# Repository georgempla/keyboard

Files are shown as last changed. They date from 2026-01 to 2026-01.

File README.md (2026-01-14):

# George’s Keyboard

After many hours of work, I designed a custom mechanical keyboard featuring RGB LEDs, OLED displays, and rotary encoders. This project focuses on PCB planning, firmware research, CAD design, and represents my second hardware project ever.

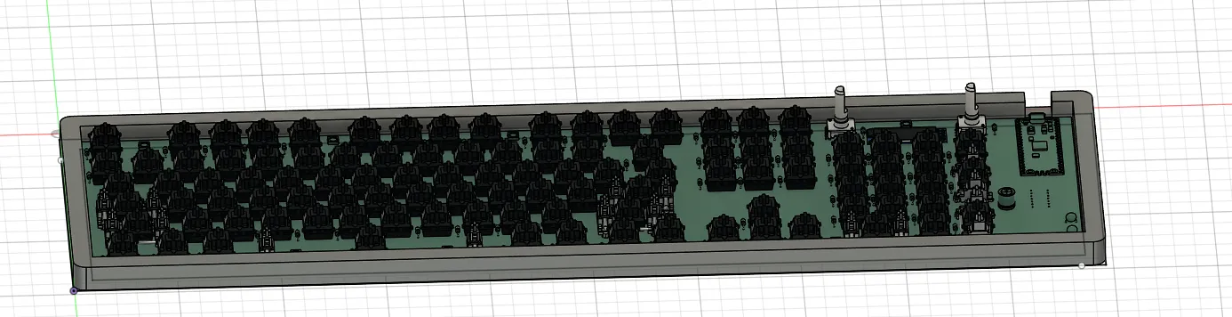
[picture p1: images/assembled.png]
Georgeskeyboardrender


---

## What This Project Is

This Project is a custom mechanical keyboard powered by a Raspberry Pi Pico. It has:
- Sections of addressable RGB LEDs
- Two rotary encoders with switches
- An OLED 0.91Inch display
- A custom PCB designed in KiCad
- A 3D-printed case that showcases the PCB

The goal of this project was to recreate my own keyboard layout while adding extra functionality and learning more about PCB design and KMK firmware.

---

## Inspiration

This was only my second project ever. While looking for ideas I realized that the inspiration was right in front of me: my own keyboard. After taking measurements and studying how keyboards in general are designed, I decided to recreate it while adding my own twist on the concept with LEDs, an OLED display, and rotary encoders.

---

## Challenges / What I Learned

This was the second PCB I havee ever designed, and the first one I designed completely on my own. Through this process, I learned:
- How to organize a KiCad project properly
- Better routing techniques
- How to recover from mistakes and reroute a board cleanly

Even though I had to redo parts of the design, the second iteration was much cleaner.

---

## Design Files

This project includes:
- A full keyboard schematic
- A routed PCB layout
- A 3D printable case design

Schematic | PCB Layout | Case
:--:|:--:|:--:
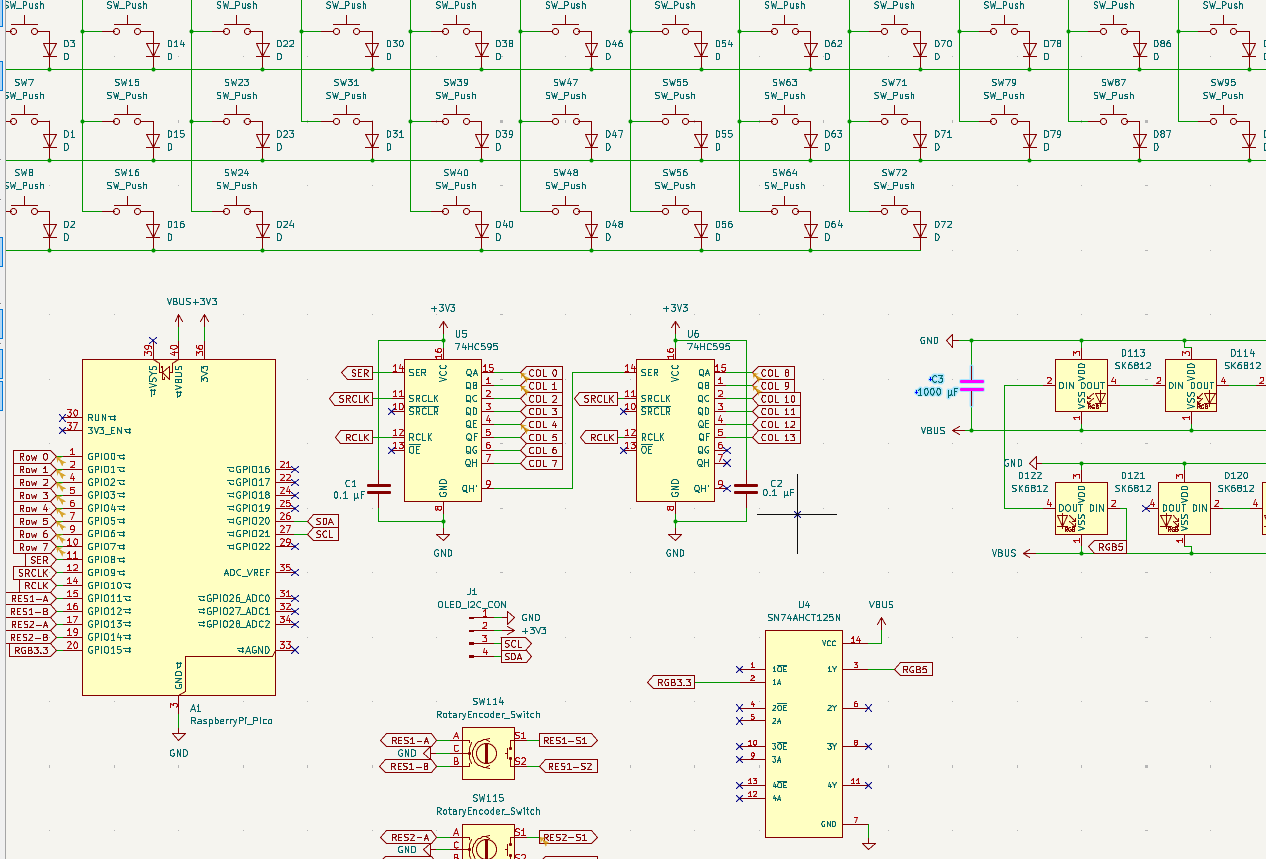
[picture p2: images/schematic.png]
schematic
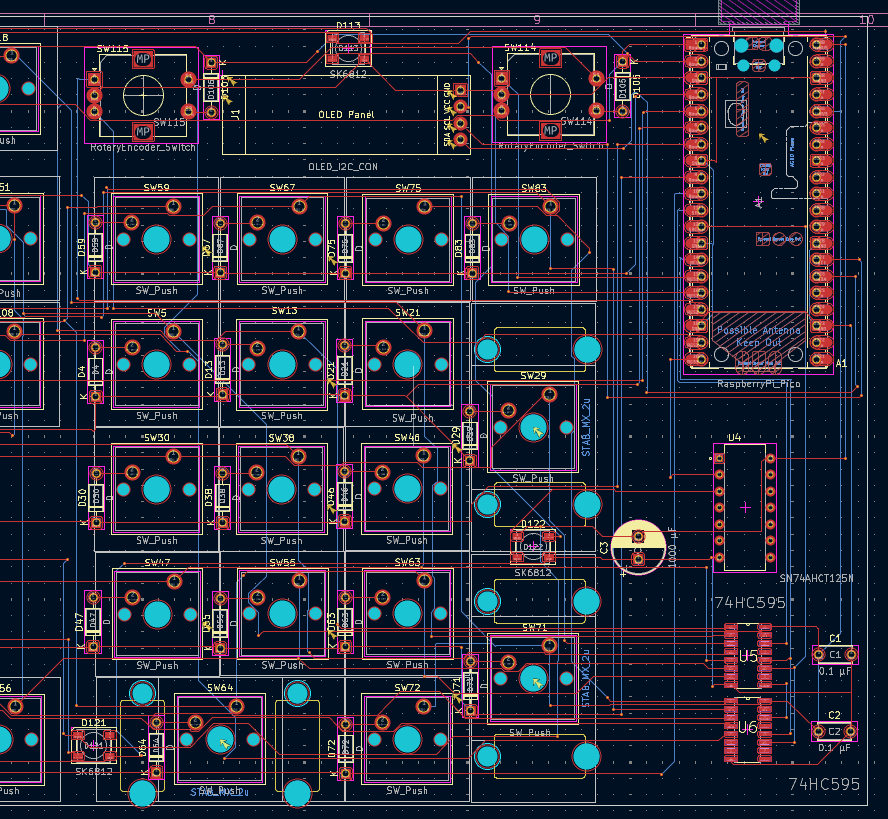
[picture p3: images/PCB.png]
pcb
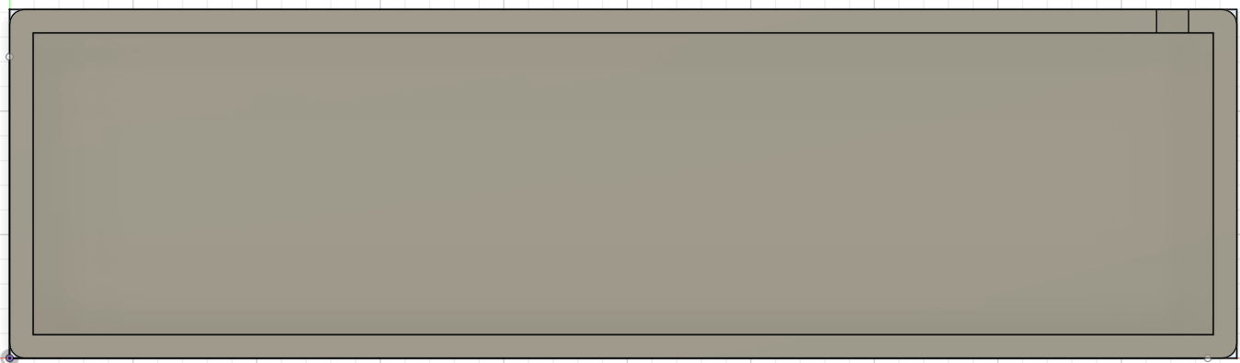
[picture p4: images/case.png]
case
 |  |  

---

## Firmware (Planned)

The firmware is currently written but *untested*, as the keyboard has not yet been assembled. Once the hardware is built I plan to:
- Flash the firmware to the Raspberry Pi Pico
- Test all keys, LEDs, encoders, and the OLED display
- Fix bugs and upload a finalized version

After testing this section will be updated with corrected code and flashing instructions.

---

## Bill of Materials (BOM)

### Electronics
- 1× Raspberry Pi Pico
- 1× OLED module (0.91", 128×32)
- 2× Rotary encoders (12 mm, 24 P/R, with switch)
- 10× SK6812 RGB LEDs
- 2× 74HCT595D shift registers
- 1× 74AHCT125
- 110× 1N4148 diodes
- 1× 1000 µF capacitor
- 2× 100 nF ceramic capacitors

### Mechanical
- Keychron K Pro switches (110 pieces)
- Glorious Stabilizers V2
- Mountain Dolomite A Backlit Keycap Set
- 3D printed case (`case.stl`)

---

## Next Steps

- Wait for approval
- Order the PCB
- Print the case
- Assemble and solder all components
- Test and debug firmware
- Update this README with build instructions

---

## Reflection

This project helped me evolve a lot as a designer. Compared to my first PCB, this one is cleaner, more complex, and better planned. Even though it isn't built yet, I learned a huge amount about schematics, routing, and hardware design through the process.

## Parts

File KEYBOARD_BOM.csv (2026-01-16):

Product name | Product description | Product amount | Product unit cost inc. Tax (€) | Product total cost (€) | Running total (€ with tax and shipping) | Notes | LINKS
OLED Module 0.91" 128x32 | OLED display module | 1 | 6.8 | 6.8 | 6.8 |  | https://grobotronics.com/oled-module-0.91-128x32-i2c-white.html
Rotary Encoder 12mm 24P/R with Switch | Rotary Encoder with Switch | 2 | 1.2 | 2.4 | 9.2 |  | https://grobotronics.com/rotary-encoder-12mm-24p-r-with-switch.html
74AHCT125 | Quad Level-Shifter | 1 | 0.5 | 0.5 | 9.7 |  | https://grobotronics.com/74ahct125-quad-level-shifter.html
SK6812 | LED SMD 5050 RGB Programmable | 10 | 0.3 | 3 | 12.7 |  | https://grobotronics.com/led-8mm-rgb-programmable-ws2812-clone.html
74HCT595D | Shift Register 8-Bit SMD | 2 | 0.8 | 1.6 | 14.3 |  | https://grobotronics.com/shift-register-8-bit-smd-74hct595d.html
Capacitor 1000uF | Electrolytic Capacitor 16V 1000uF | 1 | 0.2 | 0.2 | 16.7 | with 2.20 shipping from grobotronics for last 6 products | https://grobotronics.com/electrolytic-capacitor-16v-1000ufoem.html
Πυκνωτής 100nf | Πυκνωτής Κεραμικός 104(100nf) | 2 | 0.05 | 0.1 | 16.8 |  | https://nettop.gr/index.php/hlektronika/capacitors/ceramic-capacitor/pyknotis-keramikos-104-100nf.html
Raspberry Pi Pico | Raspberry Pi Pico without Headers | 1 | 4.2 | 4.2 | 21 |  | https://nettop.gr/index.php/raspberry-pi/pico/raspberry-pi-pico.html?src=raspberrypi
1N4148 | Diode - 1N4148 Small Signal Fast Switching Diode | 110 | 0.04 | 4.4 | 27.7 | with 2.30 shipping from nettop for last 3 products | https://nettop.gr/index.php/hlektronika/diode/diode-1n4148-small-signal-fast-switching-diode.html
Keychron K Pro Switches | Keychron K Pro Switches Πληκτρολογίου, 110-pack | 1 | 17.48 | 17.48 | 45.18 | in-store pickup | https://www.public.gr/product/gaming/pc-gaming/pc-gaming-accessories/diafora-pc-gaming-accessories/keychron-k-pro-switches-pliktrologiou-110-pack/2090270
Glorious Stabilizers V2 | Glorious Stabilizers V2 | 1 | 4.99 | 4.99 | 50.17 |  | https://shopflix.gr/p/SF-12868640/stabilizers-glorious-v2-gata1723-12843162
Mountain Dolomite A Backlit Keycap Set | Mountain Dolomite A Backlit Keycap Set | 1 | 5.25 | 5.25 | 60.42 | with 5 shipping from shopflix for last 2 products | https://www.skroutz.gr/s/57409660/Mountain-Dolomite-A-Backlit-Keycap-Set.html
PCB | PCB for JLCPCB | 42.33 | 42.33 | 42.33 | 102.75 | with cheapest shipping | https://shopflix.gr/p/SF-200097568/mountain-dolomite-a-backlit-keycap-set
 |  |  |  |  |  |  | https://jlcpcb.com

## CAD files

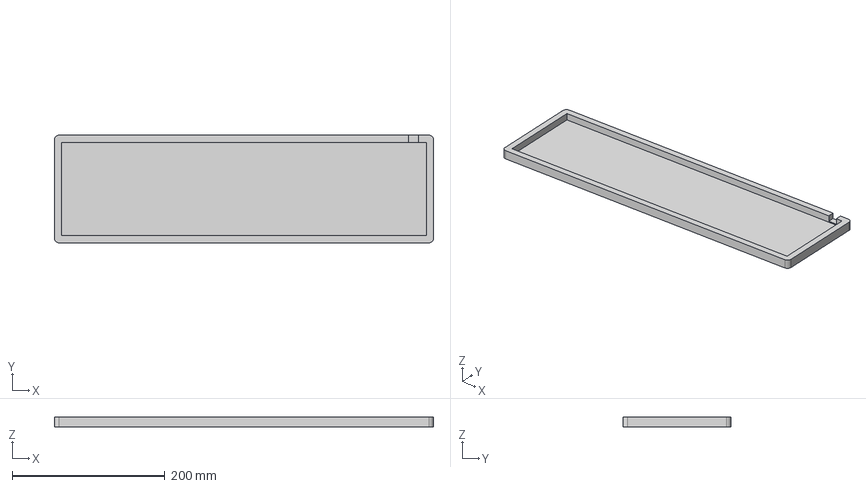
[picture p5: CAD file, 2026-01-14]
CAD/Keyboard.step
496.7 x 141.2 x 13.0 mm

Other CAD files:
CAD/case.stl

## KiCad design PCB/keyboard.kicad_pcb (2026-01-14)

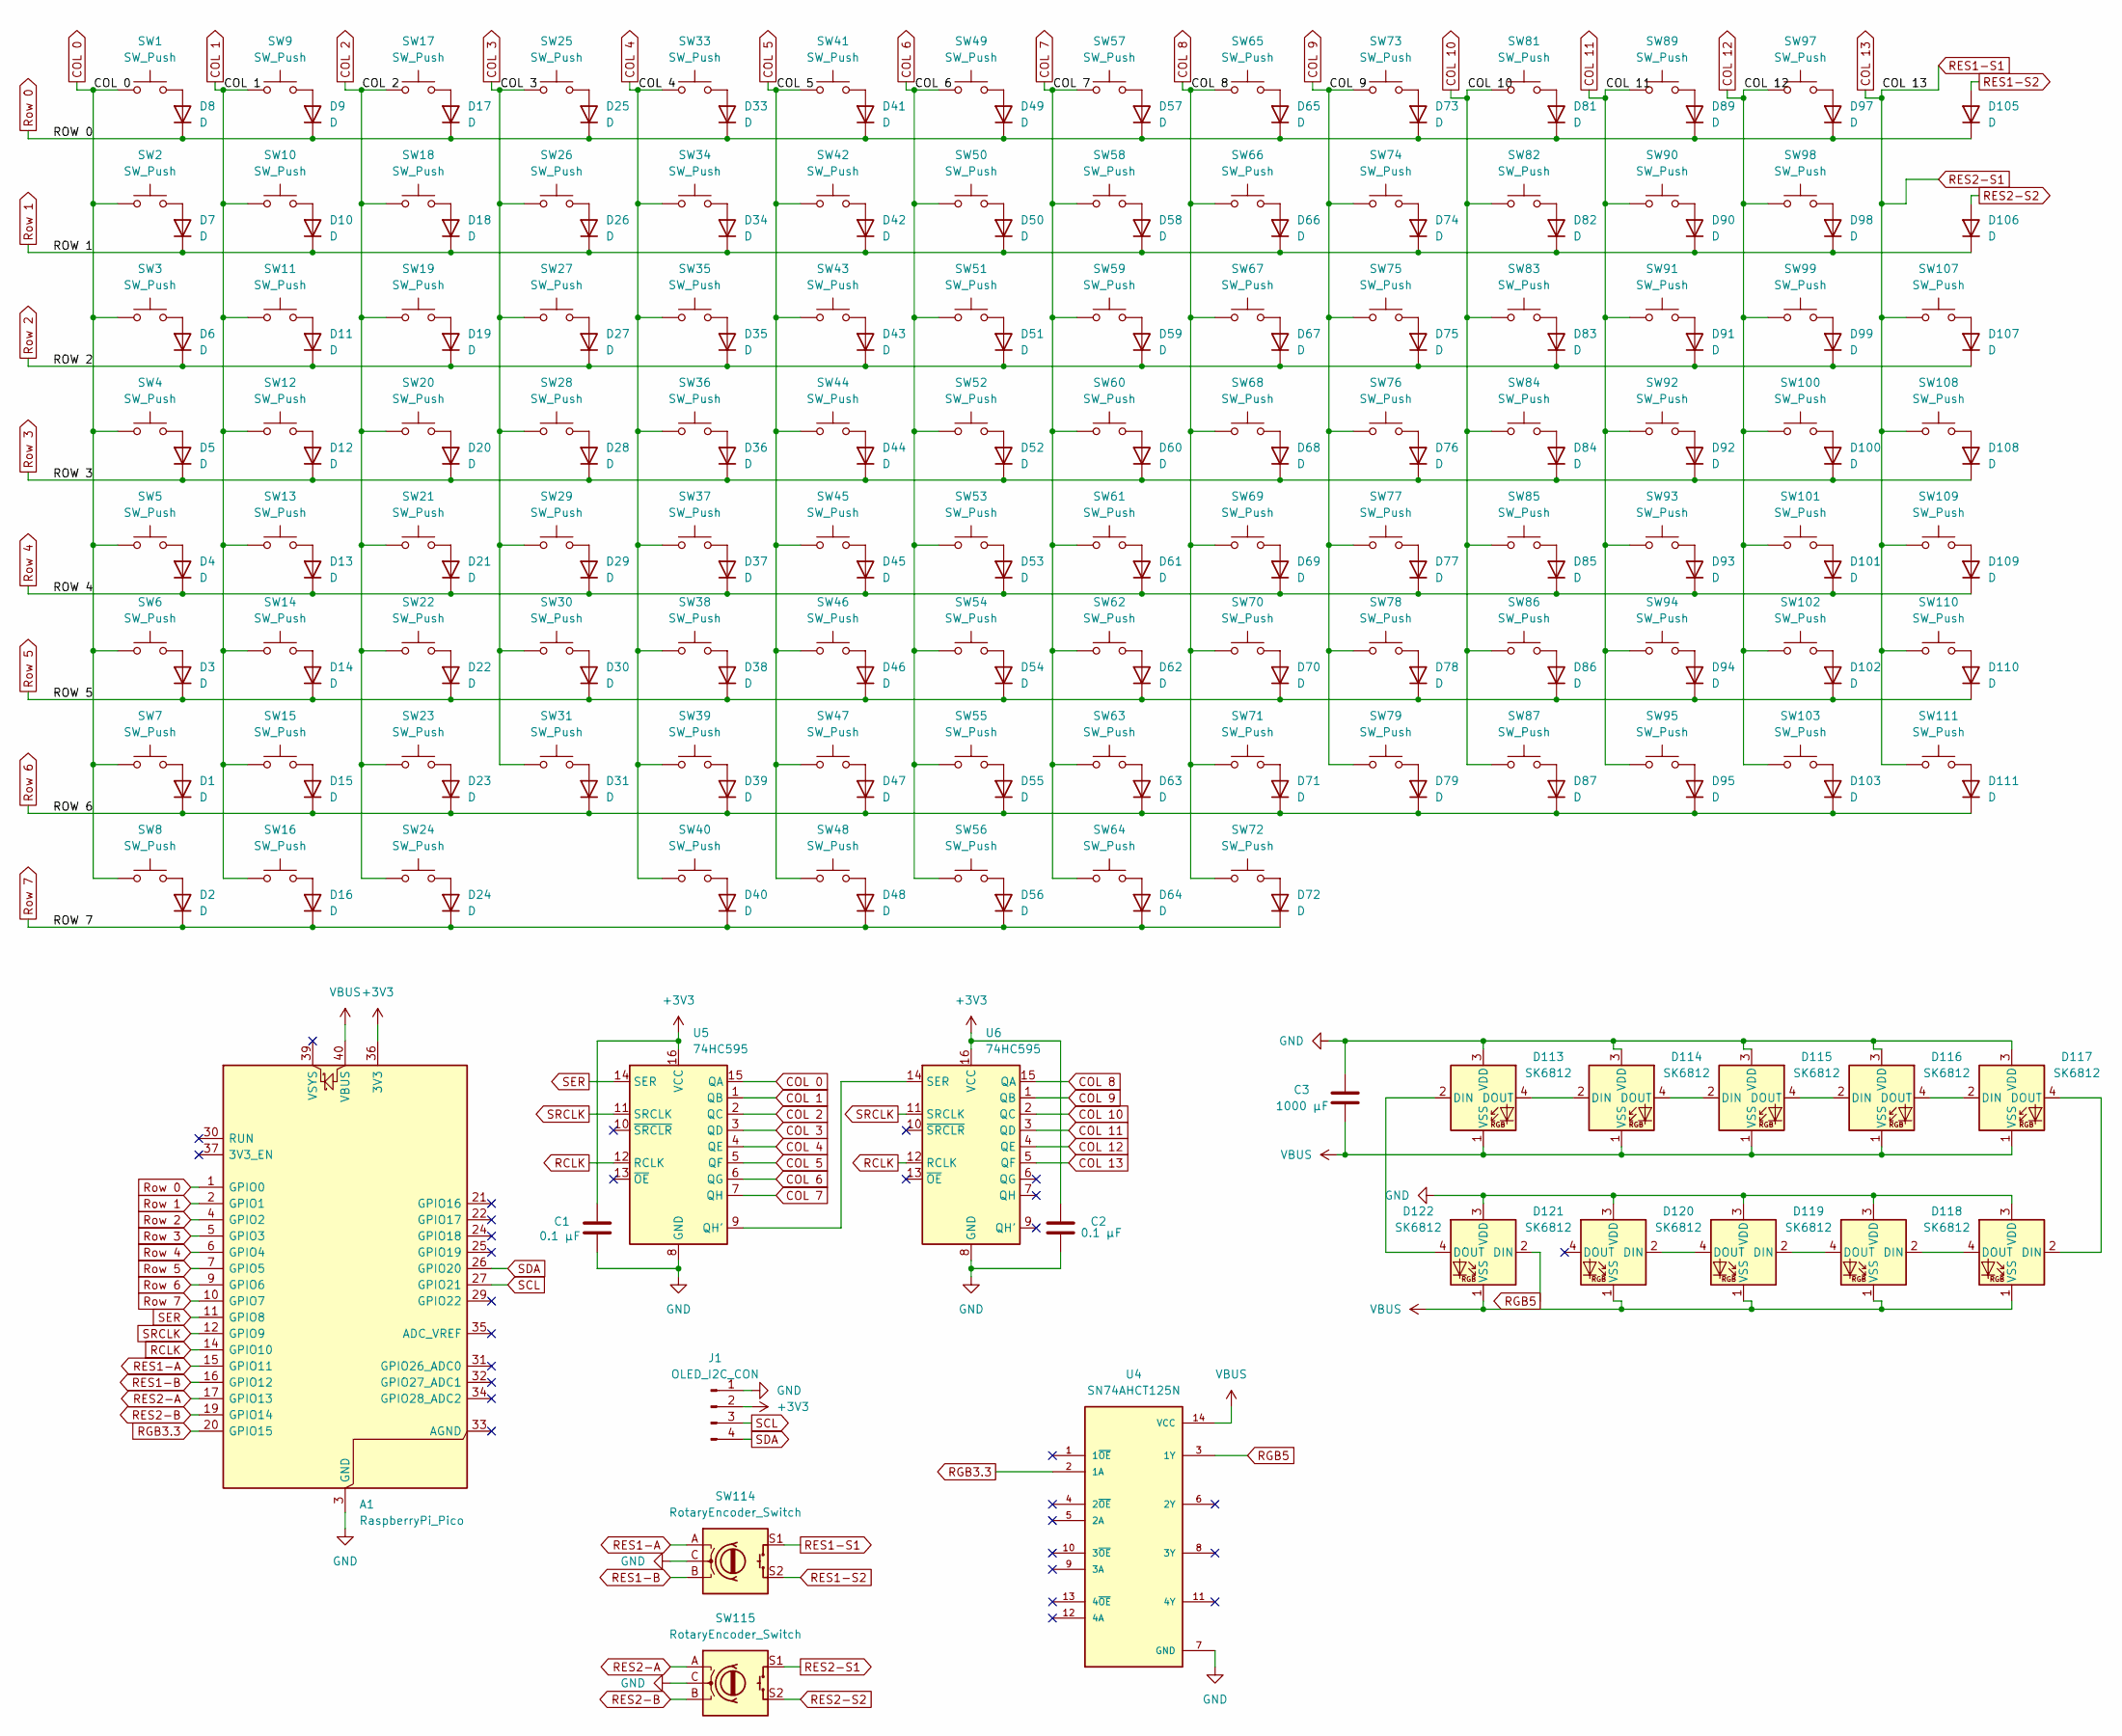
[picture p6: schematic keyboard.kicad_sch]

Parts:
A1: RaspberryPi_Pico; RaspberryPi_Pico_Common_Unspecified
C1, C2: 0.1 µF; C_Disc_D5.0mm_W2.5mm_P5.00mm
C3: 1000 µF; CP_Radial_D8.0mm_P3.50mm
D1, D2, D3, D4, D5, D6, D7, D8, D9, D10, D11, D12, D13, D14, D15, D16, D17, D18, D19, D20, D21, D22, D23, D24, D25, D26, D27, D28, D29, D30, D31, D33, D34, D35, D36, D37, D38, D39, D40, D41, D42, D43, D44, D45, D46, D47, D48, D49, D50, D51, D52, D53, D54, D55, D56, D57, D58, D59, D60, D61, D62, D63, D64, D65, D66, D67, D68, D69, D70, D71, D72, D73, D74, D75, D76, D77, D78, D79, D81, D82, D83, D84, D85, D86, D87, D89, D90, D91, D92, D93, D94, D95, D97, D98, D99, D100, D101, D102, D103, D105, D106, D107, D108, D109, D110, D111: D; D_DO-35_SOD27_P7.62mm_Horizontal
D113, D114, D115, D116, D117, D118, D119, D120, D121, D122: SK6812; LED_SK6812_PLCC4_5.0x5.0mm_P3.2mm
J1: OLED_I2C_CON; 0.91 OLED 128x32
SW1, SW2, SW3, SW4, SW5, SW6, SW7, SW8, SW9, SW10, SW11, SW12, SW13, SW14, SW15, SW16, SW17, SW18, SW19, SW20, SW21, SW22, SW23, SW24, SW25, SW26, SW27, SW28, SW29, SW30, SW31, SW33, SW34, SW35, SW36, SW37, SW38, SW39, SW40, SW41, SW42, SW43, SW44, SW45, SW46, SW47, SW48, SW49, SW50, SW51, SW52, SW53, SW54, SW55, SW56, SW57, SW58, SW59, SW60, SW61, SW62, SW63, SW64, SW65, SW66, SW67, SW68, SW69, SW70, SW71, SW72, SW73, SW74, SW75, SW76, SW77, SW78, SW79, SW81, SW82, SW83, SW84, SW85, SW86, SW87, SW89, SW90, SW91, SW92, SW93, SW94, SW95, SW97, SW98, SW99, SW100, SW101, SW102, SW103, SW107, SW108, SW109, SW110, SW111: SW_Push; SW_Cherry_MX_1.00u_PCB
SW114, SW115: RotaryEncoder_Switch; RotaryEncoder_Alps_EC12E-Switch_Vertical_H20mm
U4: SN74AHCT125N; DIP794W45P254L1930H508Q14; PARTREV Q
U5, U6: 74HC595; SOIC127P600X175-16N

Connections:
+3V3: A1.36 (3V3), C1.1, C2.1, J1.2, U5.16 (VCC), U6.16 (VCC)
COL 0: SW1.1, SW2.1, SW3.1, SW4.1, SW5.1, SW6.1, SW7.1, SW8.1, U5.15 (QA)
COL 1: SW9.1, SW10.1, SW11.1, SW12.1, SW13.1, SW14.1, SW15.1, SW16.1, U5.1 (QB)
COL 2: SW17.1, SW18.1, SW19.1, SW20.1, SW21.1, SW22.1, SW23.1, SW24.1, U5.2 (QC)
COL 3: SW25.1, SW26.1, SW27.1, SW28.1, SW29.1, SW30.1, SW31.1, U5.3 (QD)
COL 4: SW33.1, SW34.1, SW35.1, SW36.1, SW37.1, SW38.1, SW39.1, SW40.1, U5.4 (QE)
COL 5: SW41.1, SW42.1, SW43.1, SW44.1, SW45.1, SW46.1, SW47.1, SW48.1, U5.5 (QF)
COL 6: SW49.1, SW50.1, SW51.1, SW52.1, SW53.1, SW54.1, SW55.1, SW56.1, U5.6 (QG)
COL 7: SW57.1, SW58.1, SW59.1, SW60.1, SW61.1, SW62.1, SW63.1, SW64.1, U5.7 (QH)
COL 8: SW65.1, SW66.1, SW67.1, SW68.1, SW69.1, SW70.1, SW71.1, SW72.1, U6.15 (QA)
COL 9: SW73.1, SW74.1, SW75.1, SW76.1, SW77.1, SW78.1, SW79.1, U6.1 (QB)
COL 10: SW81.1, SW82.1, SW83.1, SW84.1, SW85.1, SW86.1, SW87.1, U6.2 (QC)
COL 11: SW89.1, SW90.1, SW91.1, SW92.1, SW93.1, SW94.1, SW95.1, U6.3 (QD)
COL 12: SW97.1, SW98.1, SW99.1, SW100.1, SW101.1, SW102.1, SW103.1, U6.4 (QE)
COL 13: SW107.1, SW108.1, SW109.1, SW110.1, SW111.1, SW114.S1, SW115.S1, U6.5 (QF)
GND: A1.3 (GND), A1.8 (GND), A1.13 (GND), A1.18 (GND), A1.23 (GND), A1.28 (GND), A1.38 (GND), C1.2, C2.2, C3.1, D113.3 (VDD), D114.3 (VDD), D115.3 (VDD), D116.3 (VDD), D117.3 (VDD), D118.3 (VDD), D119.3 (VDD), D120.3 (VDD), D121.3 (VDD), D122.3 (VDD), J1.1, SW114.C, SW115.C, U4.7 (GND), U5.8 (GND), U6.8 (GND)
unnamed: D1.2 (A), SW7.2
unnamed: D2.2 (A), SW8.2
unnamed: D3.2 (A), SW6.2
unnamed: D4.2 (A), SW5.2
unnamed: D5.2 (A), SW4.2
unnamed: D6.2 (A), SW3.2
unnamed: D7.2 (A), SW2.2
unnamed: D8.2 (A), SW1.2
unnamed: D9.2 (A), SW9.2
unnamed: D10.2 (A), SW10.2
unnamed: D11.2 (A), SW11.2
unnamed: D12.2 (A), SW12.2
unnamed: D13.2 (A), SW13.2
unnamed: D14.2 (A), SW14.2
unnamed: D15.2 (A), SW15.2
unnamed: D16.2 (A), SW16.2
unnamed: D17.2 (A), SW17.2
unnamed: D18.2 (A), SW18.2
unnamed: D19.2 (A), SW19.2
unnamed: D20.2 (A), SW20.2
unnamed: D21.2 (A), SW21.2
unnamed: D22.2 (A), SW22.2
unnamed: D23.2 (A), SW23.2
unnamed: D24.2 (A), SW24.2
unnamed: D25.2 (A), SW25.2
unnamed: D26.2 (A), SW26.2
unnamed: D27.2 (A), SW27.2
unnamed: D28.2 (A), SW28.2
unnamed: D29.2 (A), SW29.2
unnamed: D30.2 (A), SW30.2
unnamed: D31.2 (A), SW31.2
unnamed: D33.2 (A), SW33.2
unnamed: D34.2 (A), SW34.2
unnamed: D35.2 (A), SW35.2
unnamed: D36.2 (A), SW36.2
unnamed: D37.2 (A), SW37.2
unnamed: D38.2 (A), SW38.2
unnamed: D39.2 (A), SW39.2
unnamed: D40.2 (A), SW40.2
unnamed: D41.2 (A), SW41.2
unnamed: D42.2 (A), SW42.2
unnamed: D43.2 (A), SW43.2
unnamed: D44.2 (A), SW44.2
unnamed: D45.2 (A), SW45.2
unnamed: D46.2 (A), SW46.2
unnamed: D47.2 (A), SW47.2
unnamed: D48.2 (A), SW48.2
unnamed: D49.2 (A), SW49.2
unnamed: D50.2 (A), SW50.2
unnamed: D51.2 (A), SW51.2
unnamed: D52.2 (A), SW52.2
unnamed: D53.2 (A), SW53.2
unnamed: D54.2 (A), SW54.2
unnamed: D55.2 (A), SW55.2
unnamed: D56.2 (A), SW56.2
unnamed: D57.2 (A), SW57.2
unnamed: D58.2 (A), SW58.2
unnamed: D59.2 (A), SW59.2
unnamed: D60.2 (A), SW60.2
unnamed: D61.2 (A), SW61.2
unnamed: D62.2 (A), SW62.2
unnamed: D63.2 (A), SW63.2
unnamed: D64.2 (A), SW64.2
unnamed: D65.2 (A), SW65.2
unnamed: D66.2 (A), SW66.2
unnamed: D67.2 (A), SW67.2
unnamed: D68.2 (A), SW68.2
unnamed: D69.2 (A), SW69.2
unnamed: D70.2 (A), SW70.2
unnamed: D71.2 (A), SW71.2
unnamed: D72.2 (A), SW72.2
unnamed: D73.2 (A), SW73.2
unnamed: D74.2 (A), SW74.2
unnamed: D75.2 (A), SW75.2
unnamed: D76.2 (A), SW76.2
unnamed: D77.2 (A), SW77.2
unnamed: D78.2 (A), SW78.2
unnamed: D79.2 (A), SW79.2
unnamed: D81.2 (A), SW81.2
unnamed: D82.2 (A), SW82.2
unnamed: D83.2 (A), SW83.2
unnamed: D84.2 (A), SW84.2
unnamed: D85.2 (A), SW85.2
unnamed: D86.2 (A), SW86.2
unnamed: D87.2 (A), SW87.2
unnamed: D89.2 (A), SW89.2
unnamed: D90.2 (A), SW90.2
unnamed: D91.2 (A), SW91.2
unnamed: D92.2 (A), SW92.2
unnamed: D93.2 (A), SW93.2
unnamed: D94.2 (A), SW94.2
unnamed: D95.2 (A), SW95.2
unnamed: D97.2 (A), SW97.2
unnamed: D98.2 (A), SW98.2
unnamed: D99.2 (A), SW99.2
unnamed: D100.2 (A), SW100.2
unnamed: D101.2 (A), SW101.2
unnamed: D102.2 (A), SW102.2
unnamed: D103.2 (A), SW103.2
unnamed: D107.2 (A), SW107.2
unnamed: D108.2 (A), SW108.2
unnamed: D109.2 (A), SW109.2
unnamed: D110.2 (A), SW110.2
unnamed: D111.2 (A), SW111.2
unnamed: D113.2 (DIN), D122.4 (DOUT)
unnamed: D113.4 (DOUT), D114.2 (DIN)
unnamed: D114.4 (DOUT), D115.2 (DIN)
unnamed: D115.4 (DOUT), D116.2 (DIN)
unnamed: D116.4 (DOUT), D117.2 (DIN)
unnamed: D117.4 (DOUT), D118.2 (DIN)
unnamed: D118.4 (DOUT), D119.2 (DIN)
unnamed: D119.4 (DOUT), D120.2 (DIN)
unnamed: D120.4 (DOUT), D121.2 (DIN)
unnamed: U5.9 (QH'), U6.14 (SER)
RCLK: A1.14 (GPIO10), U5.12 (RCLK), U6.12 (RCLK)
RES1-A: A1.15 (GPIO11), SW114.A
RES1-B: A1.16 (GPIO12), SW114.B
RES1-S2: D105.2 (A), SW114.S2
RES2-A: A1.17 (GPIO13), SW115.A
RES2-B: A1.19 (GPIO14), SW115.B
RES2-S2: D106.2 (A), SW115.S2
RGB3.3: A1.20 (GPIO15), U4.2 (1A)
RGB5: D122.2 (DIN), U4.3 (1Y)
Row 0: A1.1 (GPIO0), D8.1 (K), D9.1 (K), D17.1 (K), D25.1 (K), D33.1 (K), D41.1 (K), D49.1 (K), D57.1 (K), D65.1 (K), D73.1 (K), D81.1 (K), D89.1 (K), D97.1 (K), D105.1 (K)
Row 1: A1.2 (GPIO1), D7.1 (K), D10.1 (K), D18.1 (K), D26.1 (K), D34.1 (K), D42.1 (K), D50.1 (K), D58.1 (K), D66.1 (K), D74.1 (K), D82.1 (K), D90.1 (K), D98.1 (K), D106.1 (K)
Row 2: A1.4 (GPIO2), D6.1 (K), D11.1 (K), D19.1 (K), D27.1 (K), D35.1 (K), D43.1 (K), D51.1 (K), D59.1 (K), D67.1 (K), D75.1 (K), D83.1 (K), D91.1 (K), D99.1 (K), D107.1 (K)
Row 3: A1.5 (GPIO3), D5.1 (K), D12.1 (K), D20.1 (K), D28.1 (K), D36.1 (K), D44.1 (K), D52.1 (K), D60.1 (K), D68.1 (K), D76.1 (K), D84.1 (K), D92.1 (K), D100.1 (K), D108.1 (K)
Row 4: A1.6 (GPIO4), D4.1 (K), D13.1 (K), D21.1 (K), D29.1 (K), D37.1 (K), D45.1 (K), D53.1 (K), D61.1 (K), D69.1 (K), D77.1 (K), D85.1 (K), D93.1 (K), D101.1 (K), D109.1 (K)
Row 5: A1.7 (GPIO5), D3.1 (K), D14.1 (K), D22.1 (K), D30.1 (K), D38.1 (K), D46.1 (K), D54.1 (K), D62.1 (K), D70.1 (K), D78.1 (K), D86.1 (K), D94.1 (K), D102.1 (K), D110.1 (K)
Row 6: A1.9 (GPIO6), D1.1 (K), D15.1 (K), D23.1 (K), D31.1 (K), D39.1 (K), D47.1 (K), D55.1 (K), D63.1 (K), D71.1 (K), D79.1 (K), D87.1 (K), D95.1 (K), D103.1 (K), D111.1 (K)
Row 7: A1.10 (GPIO7), D2.1 (K), D16.1 (K), D24.1 (K), D40.1 (K), D48.1 (K), D56.1 (K), D64.1 (K), D72.1 (K)
SCL: A1.27 (GPIO21), J1.3
SDA: A1.26 (GPIO20), J1.4
SER: A1.11 (GPIO8), U5.14 (SER)
SRCLK: A1.12 (GPIO9), U5.11 (SRCLK), U6.11 (SRCLK)
VBUS: A1.40 (VBUS), C3.2, D113.1 (VSS), D114.1 (VSS), D115.1 (VSS), D116.1 (VSS), D117.1 (VSS), D118.1 (VSS), D119.1 (VSS), D120.1 (VSS), D121.1 (VSS), D122.1 (VSS), U4.14 (VCC)

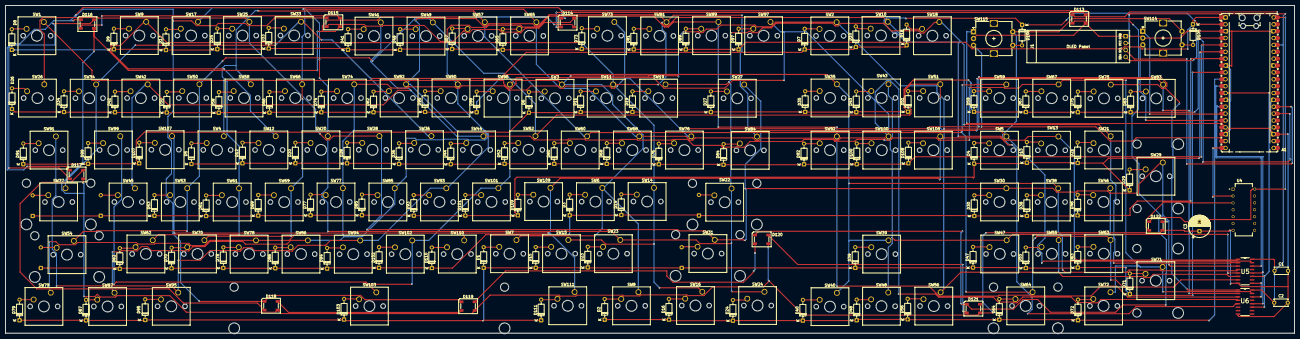
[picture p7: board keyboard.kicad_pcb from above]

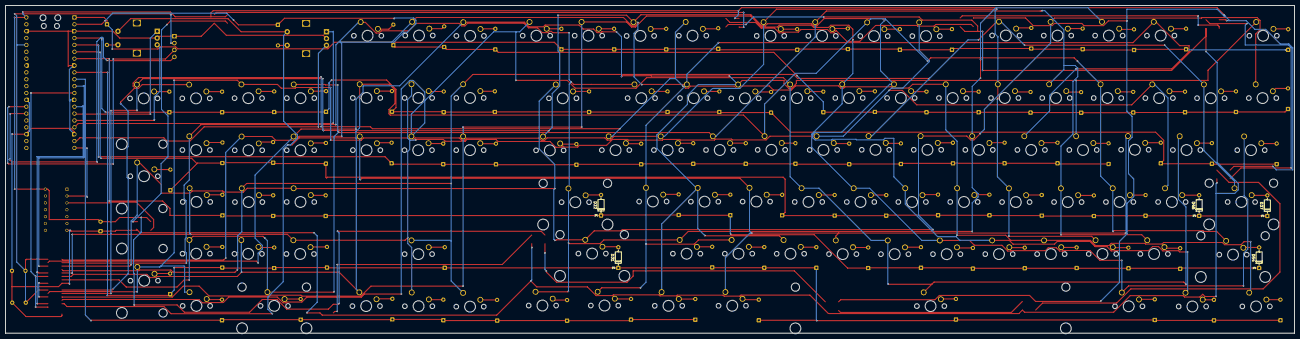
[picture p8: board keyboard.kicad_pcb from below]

Board: 2 copper layers, 476.7 x 121.2 mm, 230 parts (5 on the bottom side), 152 nets.

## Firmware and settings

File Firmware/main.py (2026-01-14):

import board
import busio
import displayio
import terminalio
import usb_cdc
import json

from adafruit_display_text import label
from adafruit_displayio_ssd1306 import SSD1306

from kmk.kmk_keyboard import KMKKeyboard
from kmk.keys import KC
from kmk.modules.encoder import EncoderHandler
from kmk.extensions.rgb import RGB

from kmk.scanners import MatrixScanner
from kmk.scanners.digitalio import DigitalioScanner
from kmk.scanners.shift_register import ShiftRegisterScanner


keyboard = KMKKeyboard()

from kmk.scanners import MatrixScanner
from kmk.scanners.digitalio import DigitalioScanner
from kmk.scanners.shift_register import ShiftRegisterScanner

ROW_PINS = (
    board.GP0,
    board.GP1,
    board.GP2,
    board.GP3,
    board.GP4,
    board.GP5,
    board.GP6,
    board.GP7,
)

COL_SHIFT_REGISTER = ShiftRegisterScanner(
    data_pin=board.GP8,
    clock_pin=board.GP9,
    latch_pin=board.GP10,
    num_cols=14,
)

keyboard.matrix = MatrixScanner(
    rows=DigitalioScanner(ROW_PINS),
    cols=COL_SHIFT_REGISTER,
    diode_orientation=MatrixScanner.DIODE_COL2ROW,
)


keyboard.keymap = [
        KC.Q, KC.W, KC.E, KC.R, KC.T, KC.Y, KC.U, KC.I, KC.O, KC.P, KC.NO, KC.NO, KC.NO, KC.NO,
        KC.A, KC.S, KC.D, KC.F, KC.G, KC.H, KC.J, KC.K, KC.L, KC.ENTER, KC.NO, KC.NO, KC.NO, KC.NO,
        KC.Z, KC.X, KC.C, KC.V, KC.B, KC.N, KC.M, KC.COMMA, KC.DOT, KC.SLASH, KC.NO, KC.NO, KC.NO, KC.NO,
        KC.ESC, KC.TAB, KC.LCTL, KC.LALT, KC.SPACE, KC.RALT, KC.RCTL, KC.LEFT, KC.DOWN, KC.UP, KC.RIGHT, KC.NO, KC.NO, KC.NO,
        KC.Q, KC.W, KC.E, KC.R, KC.T, KC.Y, KC.U, KC.I, KC.O, KC.P, KC.NO, KC.NO, KC.NO, KC.NO,
        KC.A, KC.S, KC.D, KC.F, KC.G, KC.H, KC.J, KC.K, KC.L, KC.ENTER, KC.NO, KC.NO, KC.NO, KC.NO,
        KC.Z, KC.X, KC.C, KC.V, KC.B, KC.N, KC.M, KC.COMMA, KC.DOT, KC.SLASH, KC.NO, KC.NO, KC.NO, KC.NO,
        KC.ESC, KC.TAB, KC.LCTL, KC.LALT, KC.SPACE, KC.RALT, KC.RCTL, KC.LEFT, KC.DOWN, KC.UP, KC.RIGHT, KC.NO, KC.NO, KC.NO
]

rgb = RGB(
    pixel_pin=board.GP0,
    num_pixels=10,
    brightness=0.3,
)
keyboard.extensions.append(rgb)

KEY_LED_MAP = {
    0: (0, 1),
    1: (2,),
    2: (3,),
    14: (4, 5),
    15: (6,),
    16: (7,),
    28: (8, 9),
}

def led_press(key, *_):
    if key.key_number in KEY_LED_MAP:
        for led in KEY_LED_MAP[key.key_number]:
            rgb.set_hsv(led, 0, 255, 255)

def led_release(*_):
    for i in range(10):
        rgb.set_hsv(i, 160, 255, 40)

keyboard.after_press_handler(led_press)
keyboard.after_release_handler(led_release)

encoders = EncoderHandler()
encoders.pins = (
    (board.GP13, board.GP14, None),
    (board.GP15, board.GP16, None),
)
encoders.map = (
    (KC.VOLD, KC.VOLU),
    (KC.BRIM, KC.BRID),
)
keyboard.modules.append(encoders)

displayio.release_displays()
i2c = busio.I2C(scl=board.GP18, sda=board.GP17)

display_bus = displayio.I2CDisplay(i2c, device_address=0x3C)
display = SSD1306(display_bus, width=128, height=64)

root = displayio.Group()
display.root_group = root

title = label.Label(terminalio.FONT, text="PICO KMK", x=0, y=8)
stats = label.Label(terminalio.FONT, text="", x=0, y=24)
status = label.Label(terminalio.FONT, text="", x=0, y=56)

root.append(title)
root.append(stats)
root.append(status)
serial = usb_cdc.data

host = {
    "cpu": 0,
    "ram": 0,
    "temp": 0,
    "time": "--:--:--",
}

def read_serial():
    if serial.connected and serial.in_waiting:
        try:
            data = json.loads(serial.readline().decode().strip())
            host.update(data)
        except Exception:
            pass
def update_display():
    stats.text = (
        f"CPU:{host['cpu']}%\n"
        f"RAM:{host['ram']}%\n"
        f"TMP:{host['temp']}C\n"
        f"{host['time']}"
    )
    caps = "ON" if keyboard.hid.keyboard_leds.caps_lock else "OFF"
    status.text = f"L{keyboard.active_layers[0]} CAPS:{caps}"
def housekeeping(kbd):
    read_serial()
    update_display()

keyboard.before_matrix_scan_handler(housekeeping)
if __name__ == "__main__":
    keyboard.go()

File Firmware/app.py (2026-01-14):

import psutil
import serial
import json
import time
import datetime
import sys

COM_PORT = "COM6"
BAUD_RATE = 115200
UPDATE_INTERVAL = 1.0

try:
    ser = serial.Serial(
        port=COM_PORT,
        baudrate=BAUD_RATE,
        timeout=1
    )
    time.sleep(2)  # allow Pico to reset
    print(f"[OK] Connected to {COM_PORT}")
except Exception as e:
    print("[ERROR] Could not open serial port")
    print(e)
    sys.exit(1)

def get_cpu_temp():
    try:
        temps = psutil.sensors_temperatures()
        if not temps:
            return None

        for name in temps:
            for entry in temps[name]:
                if entry.current:
                    return int(entry.current)
    except Exception:
        pass

    return None

print("[INFO] Sending stats to Pico... Press CTRL+C to stop")

try:
    while True:
        cpu = int(psutil.cpu_percent(interval=None))
        ram = int(psutil.virtual_memory().percent)
        temp = get_cpu_temp()
        now = datetime.datetime.now().strftime("%H:%M:%S")

        payload = {
            "cpu": cpu,
            "ram": ram,
            "temp": temp if temp is not None else 0,
            "time": now,
            "status": "ONLINE"
        }

        message = json.dumps(payload) + "\n"
        ser.write(message.encode("utf-8"))

        print("→", payload)
        time.sleep(UPDATE_INTERVAL)

except KeyboardInterrupt:
    print("\n[STOPPED]")

finally:
    ser.close()

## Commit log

2026-01-07 initial schematic upload
    [keyboard.kicad_pcb, keyboard.kicad_sch]
2026-01-14 First iteration
    [KEYBOARD_BOM.xlsx, Keyboard.step, case.stl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]
2026-01-15 added bom .csv
    [KEYBOARD_BOM.csv]
2026-01-16 Updated BOM to include product links
    [KEYBOARD_BOM.csv, KEYBOARD_BOM.xlsx]
